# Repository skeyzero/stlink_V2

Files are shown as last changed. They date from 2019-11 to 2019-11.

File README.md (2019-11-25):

# STLink V2  Designed with KiCAD

## 说明  
本工程为Kicad工程，里面提供改硬件对应固件。使用说明请往下看。    

## 使用说明:
1.通过别的下载器将固件烧录进去。烧录成功后插入电脑能检测到stlink设备。   
2.打开stm32 ST-Link Utility.选择 ST-Link -> Firmware update 刷路最新固件。(这里通过usb更新固件,并非通过别的下载器更新)。    
3.完毕。 

## 原理图
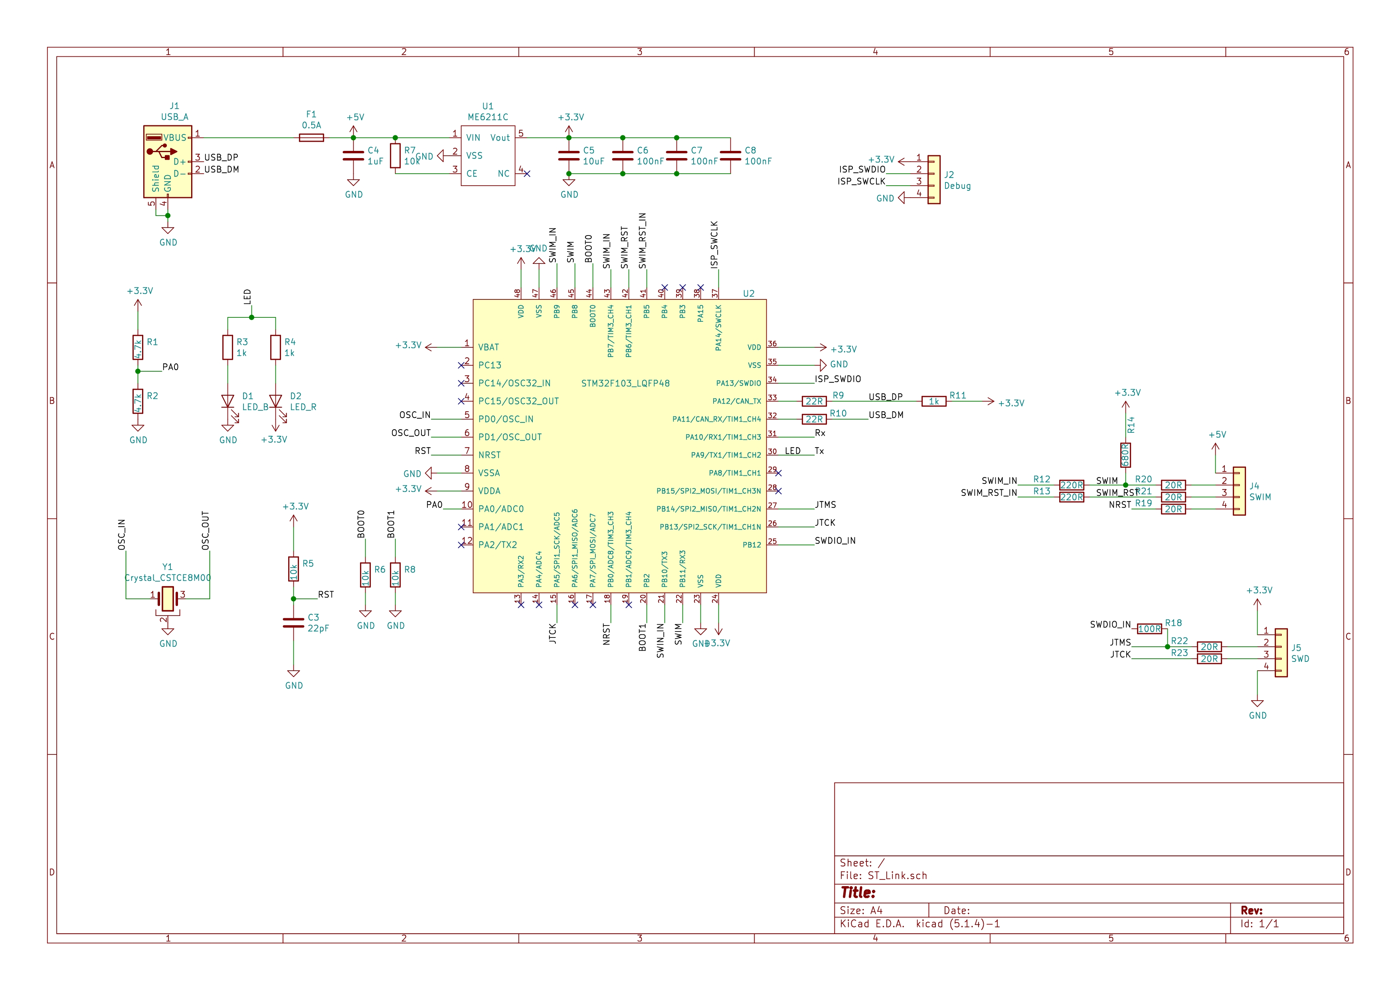
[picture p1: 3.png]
 

## 效果图   
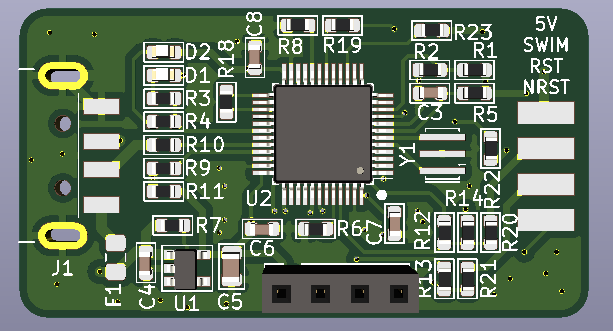
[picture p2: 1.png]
   
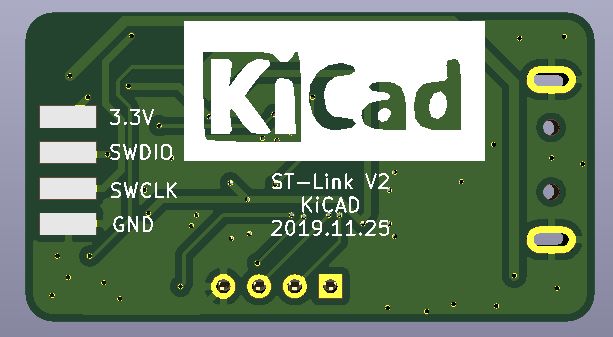
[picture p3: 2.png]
   

## 友情广告
PCB设计推荐软件Kicad，功能强大，开源免费,免除律师函警告。       
QQ群:924407324

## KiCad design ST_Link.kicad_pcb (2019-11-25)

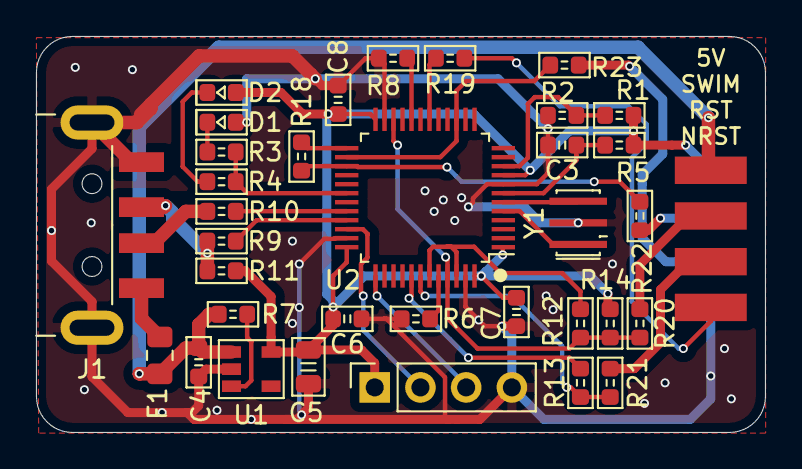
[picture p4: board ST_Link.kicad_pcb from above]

Board: 2 copper layers, 40.5 x 22.0 mm, 36 parts (1 on the bottom side), 33 nets.

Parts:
C3: 22pF; 0603_C
C4: 1uF; 0603_C
C5: 10uF; 0805_C
C6, C7, C8: 100nF; 0603_C
D1: LED_B; 0603_LED
D2: LED_R; 0603_LED
F1: 0.5A; Fuse_0805_2012Metric_Pad1.15x1.40mm_HandSolder
J1: USB_A; USB_A_CNCTech_1001-011-01101_Horizontal
J2: Debug; PinSocket_1x04_P2.54mm_Vertical
J4: SWIM; cn_smt_2.54
J5: SWD; cn_smt_2.54
R1, R2: 4.7k; 0603_R
R3, R4, R11: 1k; 0603_R
R5, R6, R7, R8: 10k; 0603_R
R9, R10: 22R; 0603_R
R12, R13: 220R; 0603_R
R14: 680R; 0603_R
R18: 100R; 0603_R
R19, R20, R21, R22, R23: 20R; 0603_R
U1: ME6211C; SOT-23-5
U2: STM32F103_LQFP48; LQFP-48_7x7mm_P0.5mm
Y1: Crystal_CSTCE8M00; Resonator_SMD_muRata_CSTxExxV-3Pin_3.0x1.1mm_HandSoldering

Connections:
+3V3: C5.1, C6.1, C7.1, C8.1, D2.1, J2.1, J5.1, R1.1, R5.1, R11.1, R14.2, U1.5, U2.1, U2.9, U2.24, U2.36, U2.48
+5V: C4.1, F1.1, J4.1, R7.1, U1.1
/BOOT0: R6.1, U2.44
/BOOT1: R8.1, U2.20
/ISP_SWCLK: J2.3, U2.37
/ISP_SWDIO: J2.2, U2.34
/JTCK: R23.2, U2.15, U2.26
/JTMS: R18.1, R22.2, U2.27
/LED: R3.1, R4.1, U2.30
/NRST: R19.2, U2.18
/OSC_IN: U2.5, Y1.1
/OSC_OUT: U2.6, Y1.3
/PA0: R1.2, R2.1, U2.10
/RST: C3.1, R5.2, U2.7
/SWDIO_IN: R18.2, U2.25
/SWIM: R12.1, R14.1, R20.2, U2.22, U2.45
/SWIM_IN: R12.2, U2.43, U2.46
/SWIM_RST: R13.1, R21.2, U2.42
/SWIM_RST_IN: R13.2, U2.41
/USB_DM: J1.2, R10.1
/USB_DP: J1.3, R9.1, R11.2
GND: C3.2, C4.2, C5.2, C6.2, C7.2, C8.2, D1.1, J1.4, J1.5, J2.4, J5.4, R2.2, R6.2, R8.2, U1.2, U2.8, U2.23, U2.35, U2.47, Y1.2
unnamed: D1.2, R3.2
unnamed: D2.2, R4.2
unnamed: F1.2, J1.1
unnamed: J4.2, R20.1
unnamed: J4.3, R21.1
unnamed: J4.4, R19.1
unnamed: J5.2, R22.1
unnamed: J5.3, R23.1
unnamed: R7.2, U1.3
unnamed: R9.2, U2.33
unnamed: R10.2, U2.32
